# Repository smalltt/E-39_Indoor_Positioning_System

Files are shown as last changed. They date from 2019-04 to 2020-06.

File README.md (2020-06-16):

# E-39 Indoor Positioning System (IPS)

**Project Status:** Ready to manufacture

If you are new to GitHub and would like to create a derivative of this project, please have a look at GitHub instructions to [fork a repo](https://help.github.com/en/articles/fork-a-repo)

## Description

Out of our passion to solve the issue of time waste in the robot creation process, ARC was born. The ARC software platform reduces the time it takes to get from idea to implementation. Since 2011 we have been listening to the challenges robot builders encounter and continue to provide them with an ever expanding toolbox of solutions. Join us on this journey!

We didn't stop at the software, we also made time saving hardware solutions. This IPS reference design is one of them. The IPS has two cameras that alternate frames. One camera has a normal lens with an Infrared blocking filter and the other has an infrared sensitive lens with a daylight blocking filter. A unique feature of this design is that it uses wide angle lenses and can detect the IPS TX at many different angles. We want to share these files with you so you can create your own version for your community and customers to enjoy!

**Features:**
- Combined with the IPS TX, this system can be used for night vision
- SWD Programming port
- Two types of communication modes: USB or EZ-B camera port
- Switch for USB or EZ-B mode
- Replaceable Camera modules
- Replaceable Wide angle lenses
- On-board 3.3V, 2.8V and 1.5V voltage regulation
- 5V tolerant I/O pins
- RGB status indicator
- ARC skill available
- Voltage requirement: 3.2-16VDC (3.3V (EZ-B) or 5V (USB) Typical)
- Current draw: 200mA
- Dimensions: 37.7(W) x 51.5(L) x 16(H) (mm)
- Weight: 11g

**Major components:** 
- STM32F407VET6 32-bit Cortex-M4 ARM microcontroller (custom firmware provided)
- 2 x HDF3M-811 OV2640 2 Megapixel Camera
- TS3DV20812RHHR 1:2 Multiplexer

**Manufacturing notes:** 
1. Supplier: programs custom firmware into the STM32F407VET6 at their facility before sending to manufacturer
2. Supplier: provides pre-built HDF3M-811 OV2640 Cameras with custom ribbon length
3. Supplier: provides HDF3M-811 OV2640 Camera with custom IR filter and Wide angle lens 
4. Supplier: provides HDF3M-811 OV2640 Camera with custom Daylight filter and Wide angle lens 
5. Manufacturer: Dual side placement and soldering of SMT components
6. Manufacturer: Single Side soldering of THT components

This project requires the IPS Transmitter: https://github.com/synthiam/E-44_IPS_Transmitter

## Contents

[**Documentation:**](https://github.com/synthiam/E-39_Indoor_Positioning_System/tree/master/E-39%20Documentation) Schematic PDF, Datasheet PDF, BOM, Assembly PDFs

[**Hardware:**](https://github.com/synthiam/E-39_Indoor_Positioning_System/tree/master/E-39%20Hardware) Altium PCB design File, Altium SCH Design File, Gerbers

[**Firmware:**](https://github.com/synthiam/E-39_Indoor_Positioning_System/tree/master/E-39%20Firmware) Code, Compiled Binary

*Altium Libraries are also available <a href="https://github.com/synthiam/Synthiam_Altium_Librairies">here</a>*

## Photos

<p align="left">


</p>

## ARC Skill

The ARC skill for this reference design is very easy to use! Simply click on the area you'd like the robot to move to and it moves there! 

Link: https://synthiam.com/Software/Manual/Indoor-Positioning-System-17492



## Contact

For profit use of these files requires written consent. Contact partners@synthiam.com. For everyone else, party on!

Synthiam Website: https://synthiam.com

## License

This project is released under the following licenses:

**Hardware:** Creative Commons Plus Attribution-NonCommercial 4.0 International (CC+ BY-NC 4.0)

**Firmware:** Apache 2.0 + “Commons Clause” License Condition v1.0

Please see [LICENSE.md](https://github.com/synthiam/E-39_Indoor_Positioning_System/blob/master/LICENSE.md) for license details.



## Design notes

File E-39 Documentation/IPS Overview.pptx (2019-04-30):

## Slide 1

Project Description:
PCB with 2 cameras and STM32 microcontroller. Both cameras are the same model. The software runs in a loop for ever. In the loop, an image from one camera is captured and transmitted out of the user specified output device (USB or UART). The next time the loop runs, the other camera is used.
The user selects the output device (UART or USB) via a selectable switch on the PCB
Output Packet
The output of each image to USB or UART includes a header. There is a header transmitted before each image. The header identifier begins with EZIMG for one camera, and EZIRC for the other camera. Following the header identifier are 4 bytes representing the image size. And finally, the image data is sent.
Header Examples
- EZIMG<4 bytes image size><image data>
- EZIRC<4 bytes image size><image data>

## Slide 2

Experience Requirements:
- STM32F407VGT6 Microcontroller
- STD Peripheral or HAL
- DCMI
- DMA
- UART
- USB

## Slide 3

Overview:
- Existing code works with UART. Now we’d like to add USB (user selectable by a switch on GPIOA_3)
- we’re okay with code being ported to work with HAL rather than STDPERIPHERAL (up to you)
- PCB has 2 i2c cameras (i2c1 & i2c2)
- STM32 has 1 DMCI interface
- The DMCI of each camera is passed through a TS3DV20812 switching chip controlled by GPIOE_4
Program Start:
- Init the peripherals and DMA, etc.
- Get the user output selected interface from GPIOA_3 switch
- Init the user selected output interface (high is UART and low is USB)
- Init each camera. If i2c fails to initialize the camera, transmit the error message using the appropriate header of the failed camera (0 EZIRC and 1 is EZIMG)
Program Loop:
- The GPIOE_4 alternates between each camera for each irritation of the loop
- The camera dumps its data into the DMA buffer
- Waits until DCMI has completed (while ((DCMI->CR & DCMI_CR_CAPTURE) != 0))
- Send the data in the buffer to the specified output interface. The output interface is user selectable with GPIOA_3 switch on bootup. (high is UART and low is USB)

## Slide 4

Camera 1

Camera 2

Switching IC

I2C1

GPIO

DCMI

I2C2

DMA

Alternate Between Camera

USB or UART selected?

Send DMA Buffer Out USB

Send DMA Buffer Out UART with RTS

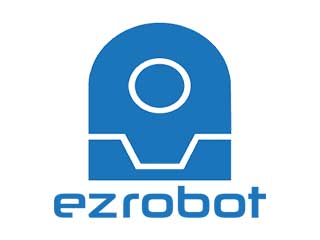
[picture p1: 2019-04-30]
E-39 Firmware/Src/LPS/ImageIntro.jpg

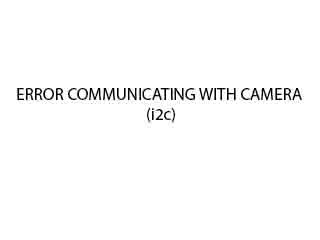
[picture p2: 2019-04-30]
E-39 Firmware/Src/LPS/ErrorCommunicating.jpg

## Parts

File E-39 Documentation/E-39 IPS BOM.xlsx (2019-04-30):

Qty | Description | Manufacturer Part No. | Alternative | Designator | Custom Information | Link
E-39 Indoor Positioning System
1 | 2 layer, Blue soldermask, White silkscreen, ENIG | IPS Printed Circuit Board |  | PCB
1 | 168MHz 32-bit ARM processor | STM32F407VET6 |  | U1 | Needs Main Firmware programmed onto chip before manufacturing | https://www.digikey.ca/product-detail/en/stmicroelectronics/STM32F407VET6/497-12075-ND/2793093
1 | 1:2 Multiplexer | TS3DV20812RHHR |  | U2 |  | https://www.digikey.ca/product-detail/en/texas-instruments/TS3DV20812RHHR/296-27631-1-ND/2345387
1 | 25MHz crystal, 18pF load, 2-SMD package | 7A-25.000MAAJ-T | ABM3-25.000MHZ-D2Y-T | XTAL |  | https://www.digikey.ca/product-detail/en/txc-corporation/7A-25.000MAAJ-T/887-1092-1-ND/2118969
1 | 2.8V Regulator SOT-25 | AP7115-28WG-7 |  | VR1 |  | https://www.digikey.ca/products/en?keywords=AP7115-28WG-7
1 | 1.5V Regulator SOT-25 | AP7331-15WG-7 |  | VR2 |  | https://www.digikey.ca/product-detail/en/diodes-incorporated/AP7331-15WG-7/AP7331-15WG-7DICT-ND/2182591
1 | 3.3V Regulator SOT-25 | SPX3819M5-L-3-3/TR |  | VR3 |  | https://www.digikey.ca/product-detail/en/maxlinear-inc/SPX3819M5-L-3-3-TR/1016-1873-1-ND/3586590
1 | FERRITE BEAD 30 OHM 0603 | CIC10P300NC |  | L1
2 | 4.7kohm 4 x Resistor Array | EXB-38V472JV |  | RA2, RA3
1 | 680ohm 4 x Resistor Array | EXB-38V681JV |  | RA1
1 | 5.1Kohm 0603 Resistor 1% | RC0603FR-075K1L |  | R1
7 | 2.2uF 16V 0603 Ceramic Capacitor | CC0603ZRY5V7BB225 |  | C1, C2, C3, C5, C6, C13, C17
8 | 0.1uF 16V 0603 Ceramic Capacitor | C0603C104K4RACTU |  | C4, C7, C8, C11, C12, C14, C15, C16
2 | 18pF 50V 0603 Ceramic Capacitor | C0603C180J5GACTU |  | C9, C10
1 | PLCC-4 (3528) RGB LED Common Anode | PLCC-4RGBCT-CA |  | RGB |  | http://ledz.com/?p=z.pricelist.other.led
2 | FPC 24pin Header | 2-1734592-4 |  | P1, P2 |  | https://www.digikey.ca/product-detail/en/2-1734592-4/A100288CT-ND/2180623
1 | 6 position JST-PH connector | B6B-PH-K-S(LF)(SN) | 00186 | P3 |  | https://www.digikey.ca/products/en?keywords=B6B-PH-K-S(LF)(SN)
1 | Polyfuse 0.5A 1206 8V | 0ZCJ0050FF2G |  | F1 |  | http://www.digikey.ca/product-detail/en/0ZCJ0050FF2G/507-1802-1-ND/4156236
1 | USB Micro B Connector | 10118194-0001LF |  | USB |  | https://www.digikey.ca/product-detail/en/amphenol-icc-fci/10118194-0001LF/609-4618-1-ND/2785382
1 | DPDT Slide Switch SMD | JS202011SCQN |  | S1 |  | https://www.digikey.ca/product-detail/en/c-k/JS202011SCQN/401-2002-1-ND/1640098
1 | OV2640 Camera + 100° Wide angle lens + Infrared filter | HDF3M-811 |  |  |  | https://www.alibaba.com/product-detail/Cheapest-2Mega-Pixel-Micro-Omnivision-OV2640_60707834599.html
1 | OV2640 Camera + 100° Wide angle lens + Daylight Filter | HDF3M-811 |  |  |  | https://www.alibaba.com/product-detail/Cheapest-2Mega-Pixel-Micro-Omnivision-OV2640_60707834599.html

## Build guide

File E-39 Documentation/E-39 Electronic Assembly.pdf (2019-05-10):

# Assembly Instructions

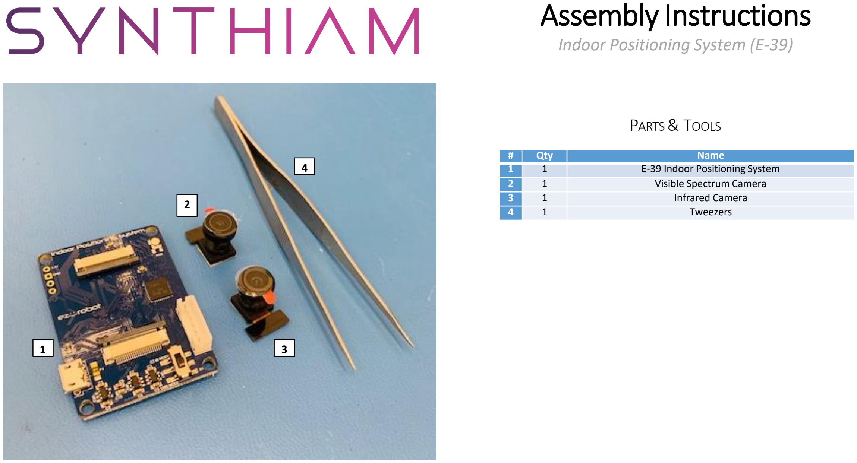
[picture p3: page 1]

# | Qty | Name

1 | 1 | E-39 Indoor Positioning System
2 | 1 | Visible Spectrum Camera
3 | 1 | Infrared Camera
4 | 1 | Tweezers

Indoor Positioning System (E-39)

PARTS & TOOLS

1

2

3

4

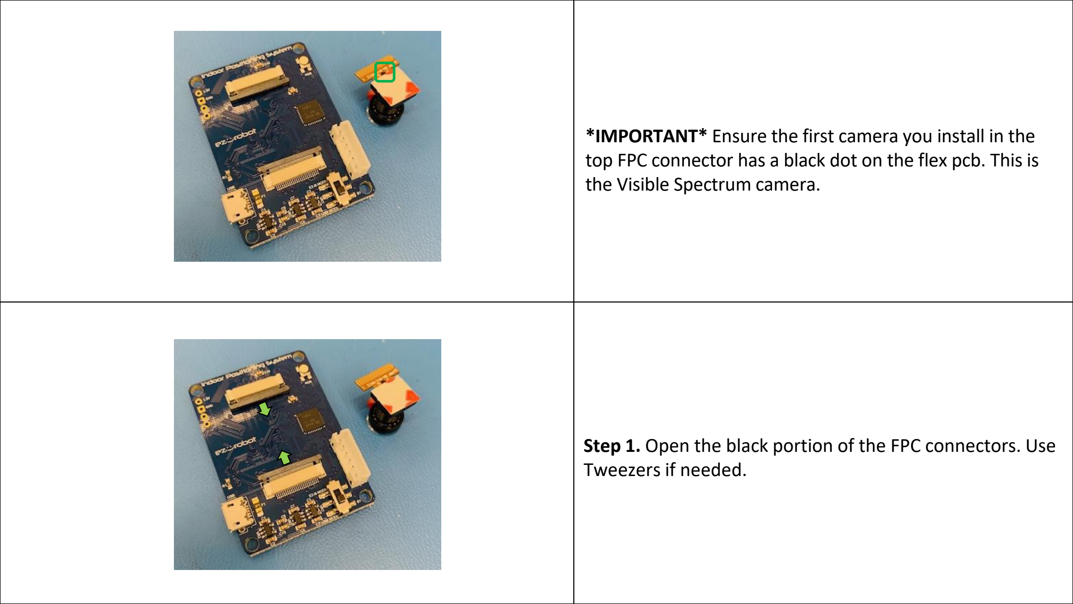
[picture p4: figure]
the Visible Spectrum camera.; Tweezers if needed.

*IMPORTANT* Ensure the first camera you install in the top FPC connector has a black dot on the flex pcb. This is

Step 1. Open the black portion of the FPC connectors. Use

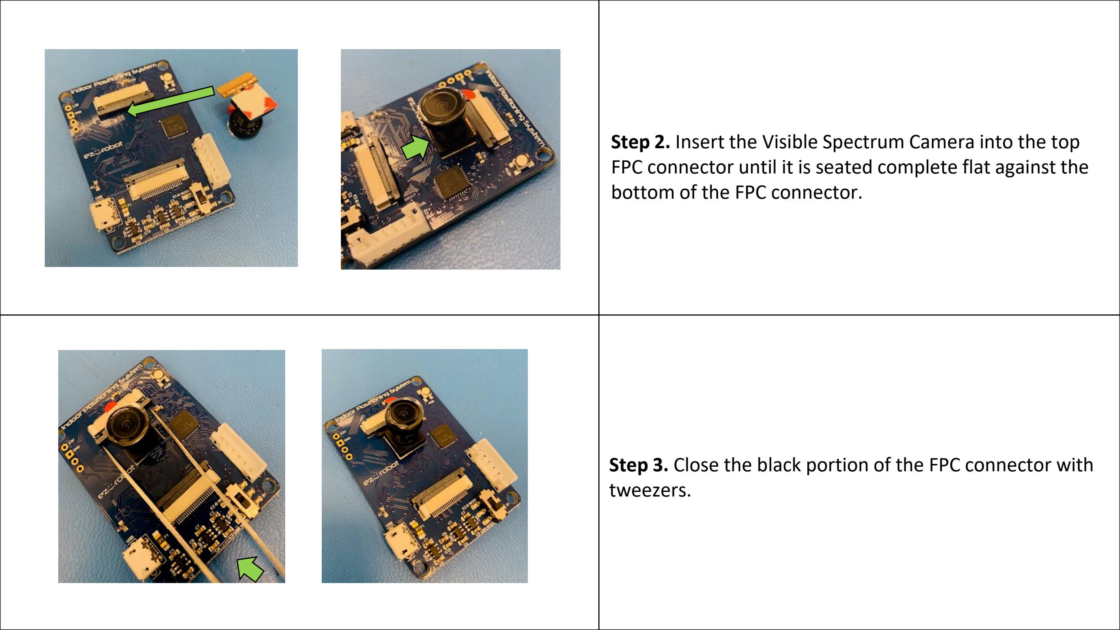
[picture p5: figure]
bottom of the FPC connector.; Infrared Filter must be Removed; tweezers.

Step 2. Insert the Visible Spectrum Camera into the top FPC connector until it is seated complete flat against the
Step 3. Close the black portion of the FPC connector with

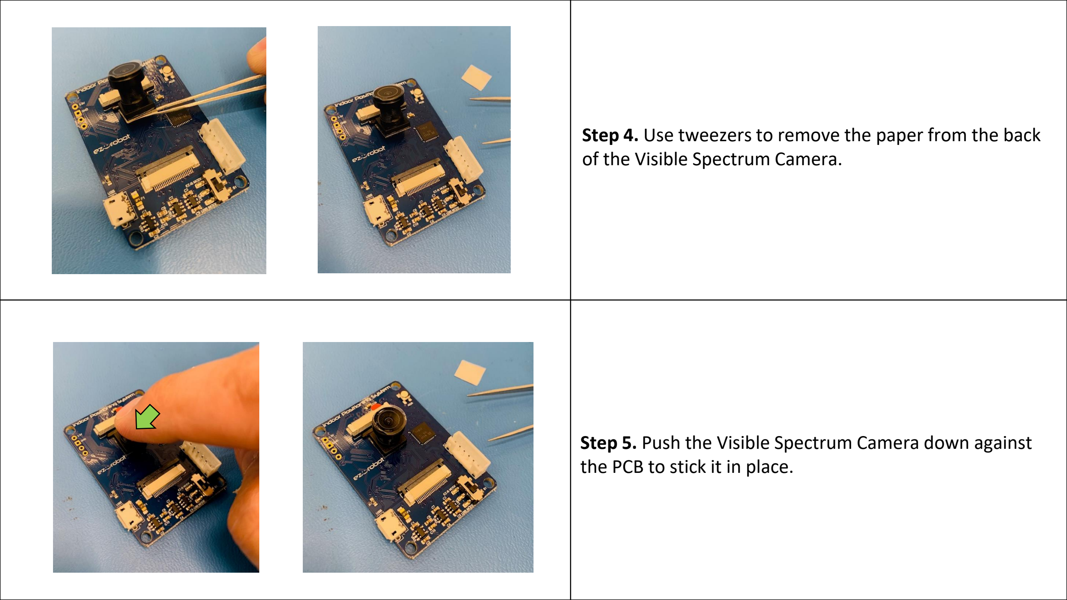
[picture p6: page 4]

Step 4. Use tweezers to remove the paper from the back of the Visible Spectrum Camera.

Infrared Filter must
be Removed
Step 5. Push the Visible Spectrum Camera down against the PCB to stick it in place.

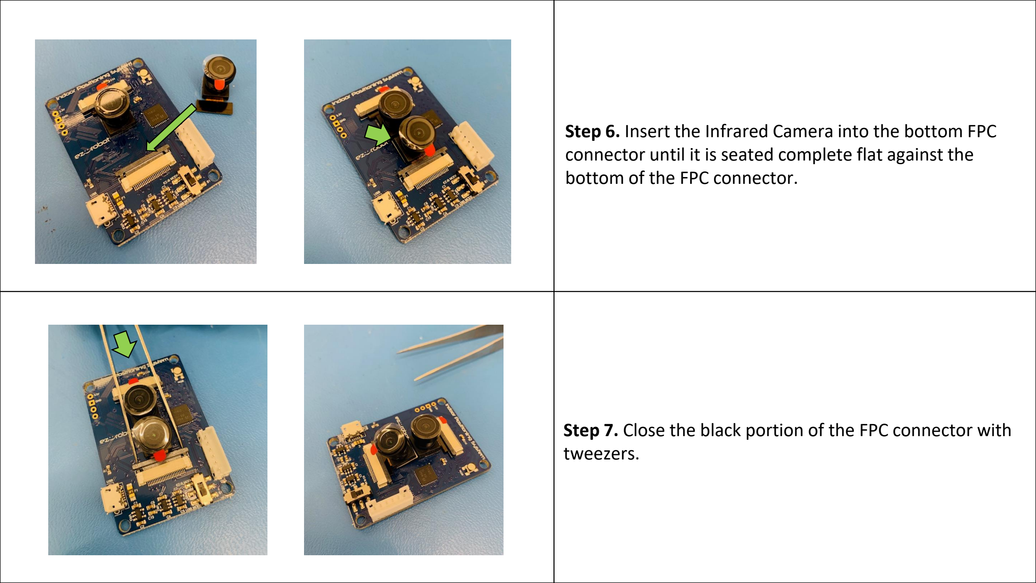
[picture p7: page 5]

Step 6. Insert the Infrared Camera into the bottom FPC connector until it is seated complete flat against the bottom of the FPC connector.

Infrared Filter must
be Removed
Step 7. Close the black portion of the FPC connector with tweezers.

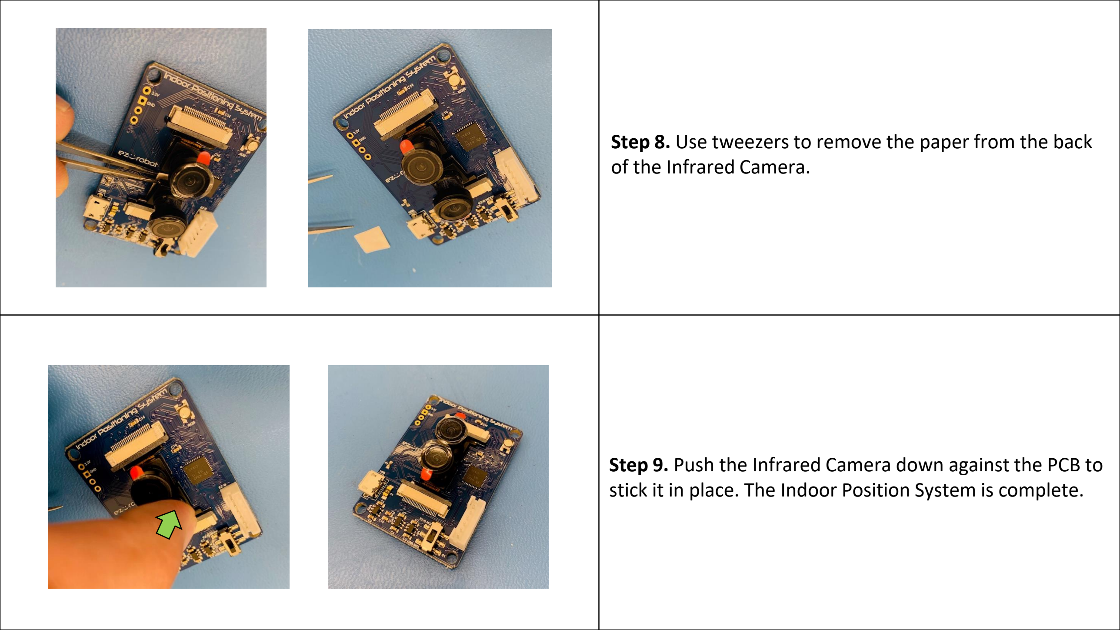
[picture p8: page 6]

Step 8. Use tweezers to remove the paper from the back of the Infrared Camera.

Infrared Filter must
be Removed
Step 9. Push the Infrared Camera down against the PCB to stick it in place. The Indoor Position System is complete.

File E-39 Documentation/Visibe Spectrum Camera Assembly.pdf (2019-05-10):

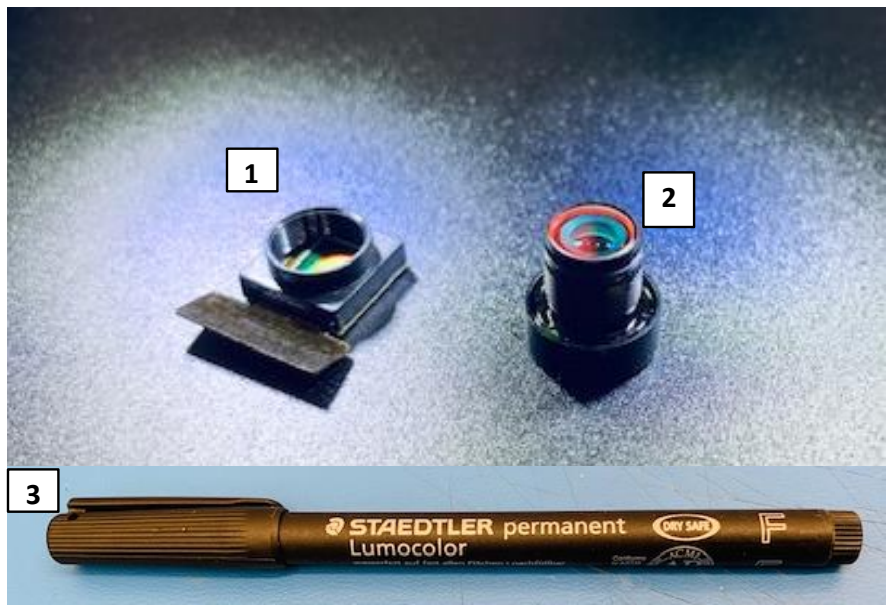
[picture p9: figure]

# | Qty | Name

1 | 1 | HDF-3M-811-WX13 Camera
2 | 1 | 100° Wide Angle Lens with 850nm Infrared filter
3 | 1 | Black permanent Marker

# Assembly Instructions

Visible Spectrum Camera + Wide Angle Lens Rev 4

PARTS & TOOLS

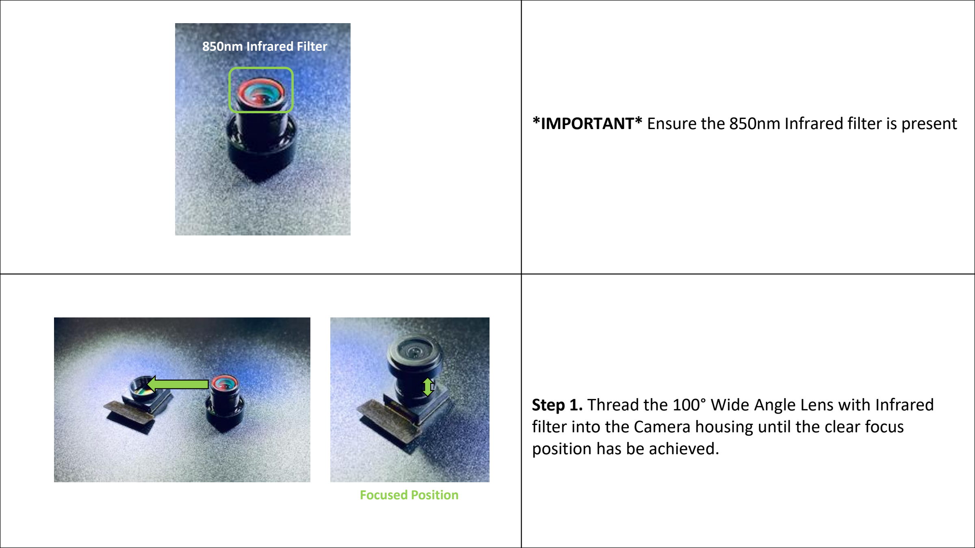
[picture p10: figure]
position has be achieved.; Focused Position; 850nm Infrared Filter

*IMPORTANT* Ensure the 850nm Infrared filter is present

Step 1. Thread the 100° Wide Angle Lens with Infrared filter into the Camera housing until the clear focus

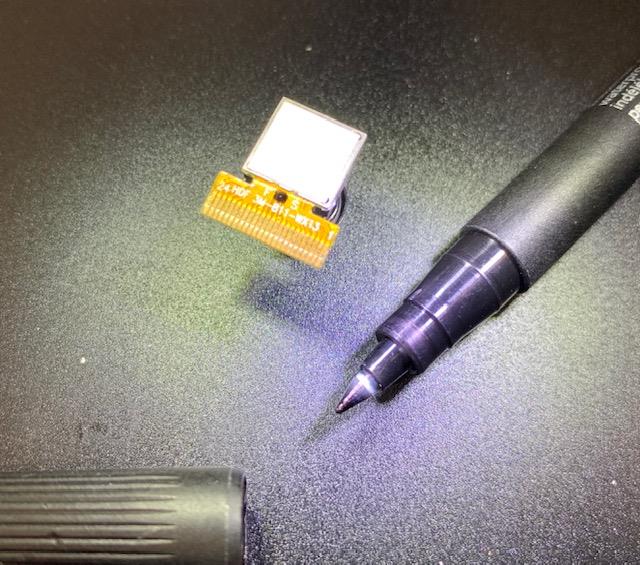
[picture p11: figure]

Step 2. Turn the camera over and place a black mark on the orange flexible PCB with the marker

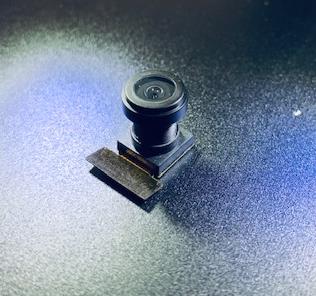
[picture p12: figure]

Visible Spectrum Camera is now complete!

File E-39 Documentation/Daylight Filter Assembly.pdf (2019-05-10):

# Assembly Instructions

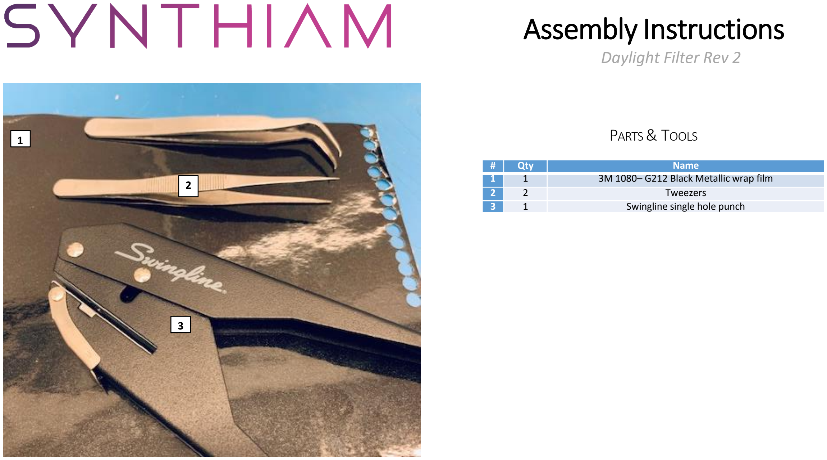
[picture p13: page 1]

# | Qty | Name

1 | 1 | 3M 1080– G212 Black Metallic wrap film
2 | 2 | Tweezers
3 | 1 | Swingline single hole punch

Daylight Filter Rev 2

PARTS & TOOLS 1

2

3

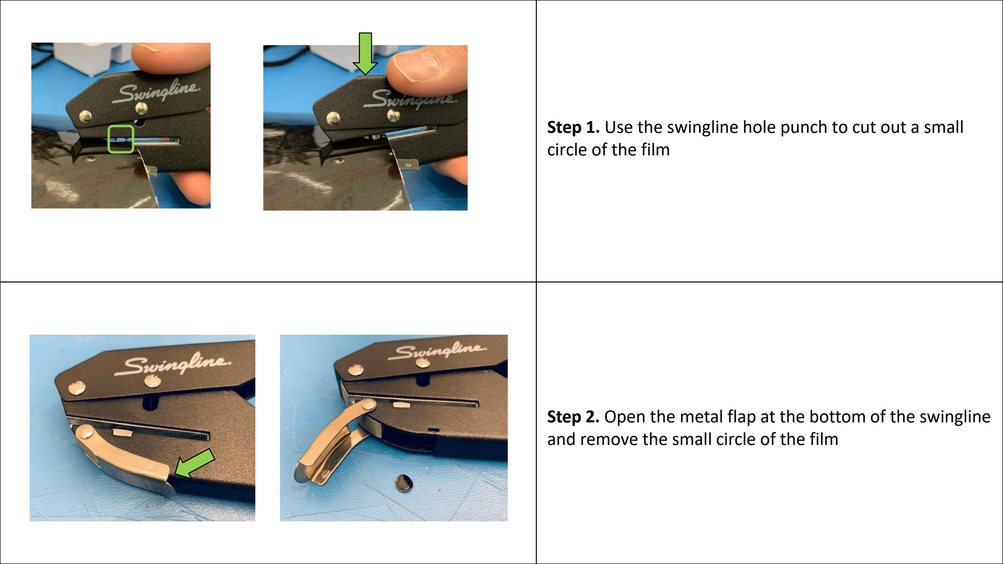
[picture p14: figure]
circle of the film; and remove the small circle of the film; 850nm Infrared Filter

Step 1. Use the swingline hole punch to cut out a small
Step 2. Open the metal flap at the bottom of the swingline

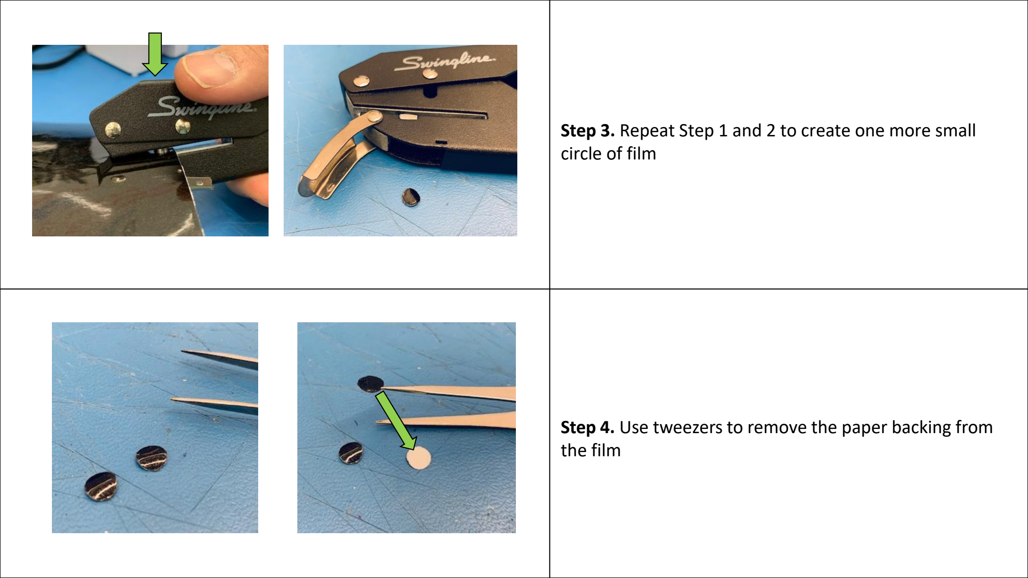
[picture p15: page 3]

Step 3. Repeat Step 1 and 2 to create one more small circle of film
Step 4. Use tweezers to remove the paper backing from the film

850nm Infrared Filter

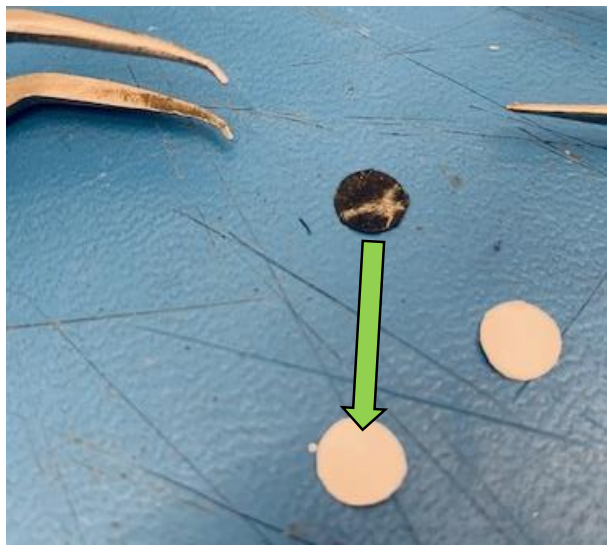
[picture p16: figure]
850nm Infrared Filter

Step 5. Use another set of tweezers to remove the paper backing from the second circle of film

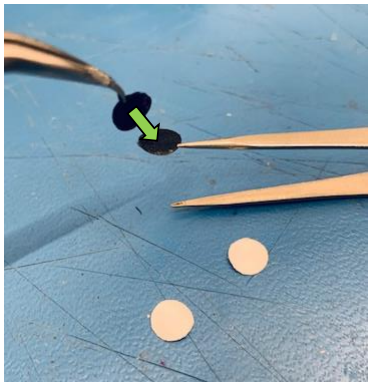
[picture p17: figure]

Step 6. Place the two small circles of film precisely on top of each other with the glue sides touching

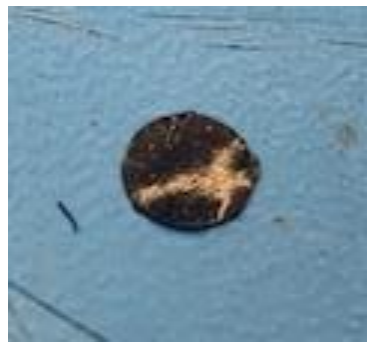
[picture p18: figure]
850nm Infrared Filter

The Daylight Filter is now Complete!

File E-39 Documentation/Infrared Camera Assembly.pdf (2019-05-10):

# Assembly Instructions

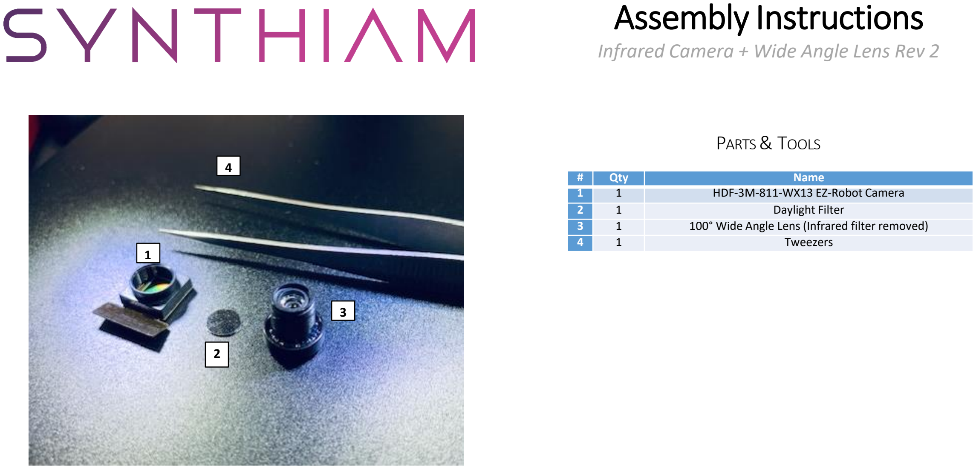
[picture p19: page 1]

# | Qty | Name

1 | 1 | HDF-3M-811-WX13 EZ-Robot Camera
2 | 1 | Daylight Filter
3 | 1 | 100° Wide Angle Lens (Infrared filter removed)
4 | 1 | Tweezers

Infrared Camera + Wide Angle Lens Rev 2

PARTS & TOOLS

1

2

3

4

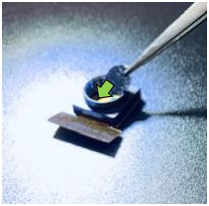
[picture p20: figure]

Step 1. Place the Daylight Filter on top of the camera CCD

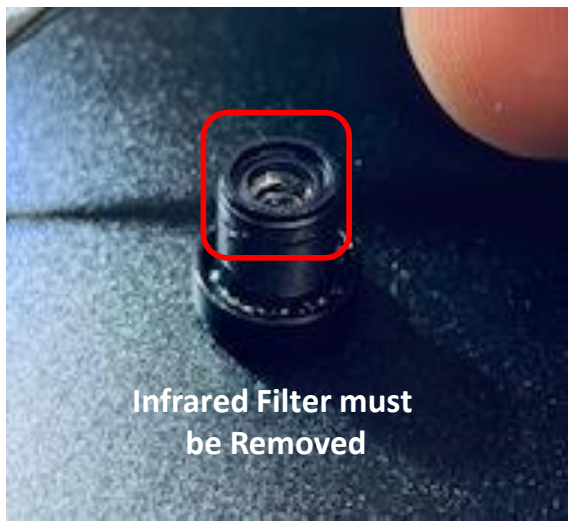
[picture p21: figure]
Infrared Filter must be Removed

*IMPORTANT* Ensure the Infrared filter is removed from the lens

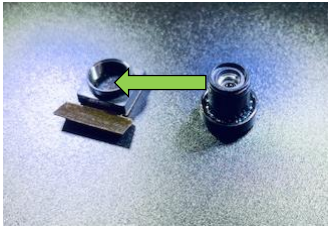
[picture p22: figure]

Step 2. Thread the 100° Wide Angle Lens into the Camera housing until the focused position has be achieved


Infrared Camera is now complete!

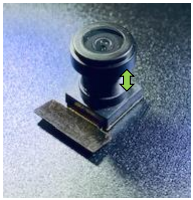
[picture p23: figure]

Focused Position

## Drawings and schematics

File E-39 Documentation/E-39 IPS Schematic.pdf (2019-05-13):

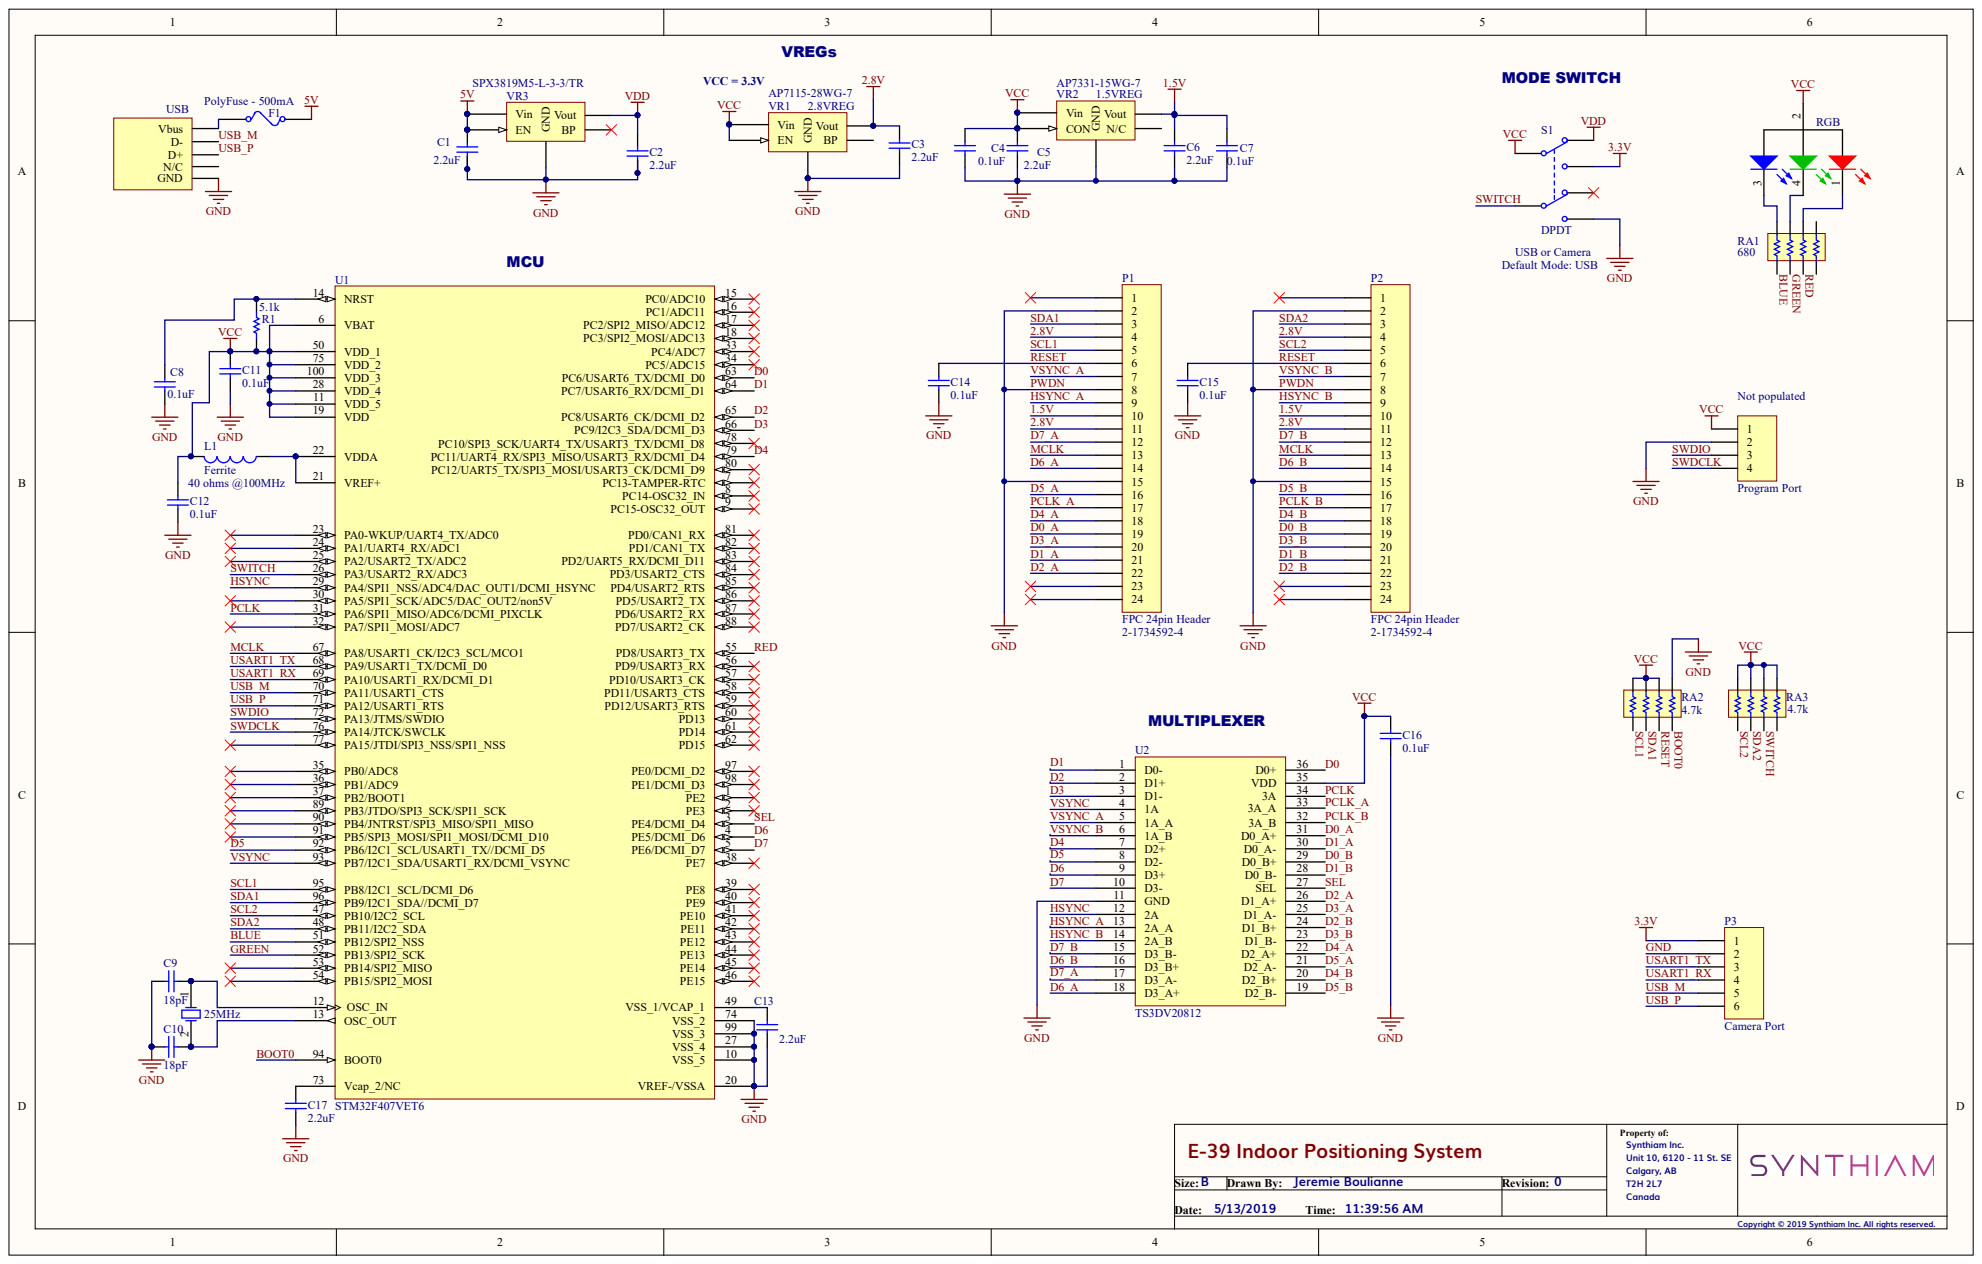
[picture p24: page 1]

E-39 Indoor Positioning System | Property of: Synthiam Inc. Unit 10, 6120 - 11 St. SE Calgary, AB T2H 2L7 Canada

B Size: | Jeremie Boulianne Drawn By: | 0 Revision:
5/13/2019 11:39:56 AM Date: Time:

Copyright © 2019 Synthiam Inc. All rights reserved.

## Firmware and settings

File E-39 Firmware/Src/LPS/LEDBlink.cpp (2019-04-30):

#include "stm32f4xx.h"
#include <stm32f4xx_gpio.h>
#include <stm32f4xx_rcc.h>
#include <stm32f4xx_i2c.h>
#include <stm32f4xx_dcmi.h>
#include <stm32f4xx_dma.h>
#include <stm32f4xx_rcc.h>
#include <stm32f4xx_exti.h>
#include <stm32f4xx_syscfg.h>
#include <stm32f4xx_flash.h>

#include "IOHelper.h"
#include <misc.h>
#include "UARTHelper.h"
#include "USBHelper.h"
#include "EZUtils.h"
#include "SCCB.h"
#include "DCMI_OV2640_INITTABLE.h"

#include "ErrorCommunicating.jpg.h"
#include "ImageIntro.jpg.h"

#define ADDR_WRITE 0x42

#define ADDR_READ 0x43

#define IMAGE_SIZE 65534

uint8_t JpegBuffer[IMAGE_SIZE];

bool _OutputInterface; // high is USB, low is UART

uint8_t _selectedCamera = 0;

void OV2640_DCMI_Config(void) {

  /* VSYNC*/
  GPIO_PinAFConfig(GPIOB, GPIO_PinSource7, GPIO_AF_DCMI);
  /* HSYNC*/
  GPIO_PinAFConfig(GPIOA, GPIO_PinSource4, GPIO_AF_DCMI);
  /* PCLK*/
  GPIO_PinAFConfig(GPIOA, GPIO_PinSource6, GPIO_AF_DCMI);
  /* data0*/
  GPIO_PinAFConfig(GPIOC, GPIO_PinSource6, GPIO_AF_DCMI);
  /* data1*/
  GPIO_PinAFConfig(GPIOC, GPIO_PinSource7, GPIO_AF_DCMI);
  /* data2*/
  GPIO_PinAFConfig(GPIOC, GPIO_PinSource8, GPIO_AF_DCMI);
  /* data3*/
  GPIO_PinAFConfig(GPIOC, GPIO_PinSource9, GPIO_AF_DCMI);
  /* data4*/
  GPIO_PinAFConfig(GPIOC, GPIO_PinSource11, GPIO_AF_DCMI);
  /* data5*/
  GPIO_PinAFConfig(GPIOB, GPIO_PinSource6, GPIO_AF_DCMI);
  /* data6*/
  GPIO_PinAFConfig(GPIOE, GPIO_PinSource5, GPIO_AF_DCMI);
  /* data7*/
  GPIO_PinAFConfig(GPIOE, GPIO_PinSource6, GPIO_AF_DCMI);

  GPIO_InitTypeDef GPIO_InitStructure;
  GPIO_InitStructure.GPIO_Pin = GPIO_Pin_4 | GPIO_Pin_6;
  GPIO_InitStructure.GPIO_Mode = GPIO_Mode_AF;
  GPIO_InitStructure.GPIO_Speed = GPIO_Speed_100MHz;
  GPIO_InitStructure.GPIO_OType = GPIO_OType_PP;
  GPIO_InitStructure.GPIO_PuPd = GPIO_PuPd_UP;
  GPIO_Init(GPIOA, &GPIO_InitStructure);

  GPIO_InitStructure.GPIO_Pin = GPIO_Pin_6 | GPIO_Pin_7;
  GPIO_InitStructure.GPIO_Mode = GPIO_Mode_AF;
  GPIO_InitStructure.GPIO_Speed = GPIO_Speed_100MHz;
  GPIO_InitStructure.GPIO_OType = GPIO_OType_PP;
  GPIO_InitStructure.GPIO_PuPd = GPIO_PuPd_UP;
  GPIO_Init(GPIOB, &GPIO_InitStructure);

  GPIO_InitStructure.GPIO_Pin = GPIO_Pin_6 | GPIO_Pin_7 | GPIO_Pin_8 | GPIO_Pin_9 | GPIO_Pin_11;
  GPIO_InitStructure.GPIO_Mode = GPIO_Mode_AF;
  GPIO_InitStructure.GPIO_Speed = GPIO_Speed_100MHz;
  GPIO_InitStructure.GPIO_OType = GPIO_OType_PP;
  GPIO_InitStructure.GPIO_PuPd = GPIO_PuPd_UP;
  GPIO_Init(GPIOC, &GPIO_InitStructure);

  GPIO_InitStructure.GPIO_Pin = GPIO_Pin_5 | GPIO_Pin_6;
  GPIO_InitStructure.GPIO_Mode = GPIO_Mode_AF;
  GPIO_InitStructure.GPIO_Speed = GPIO_Speed_100MHz;
  GPIO_InitStructure.GPIO_OType = GPIO_OType_PP;
  GPIO_InitStructure.GPIO_PuPd = GPIO_PuPd_UP;
  GPIO_Init(GPIOE, &GPIO_InitStructure);

  DCMI_InitTypeDef DCMI_InitStructure;
  DCMI_InitStructure.DCMI_CaptureMode = DCMI_CaptureMode_SnapShot;
  DCMI_InitStructure.DCMI_ExtendedDataMode = DCMI_ExtendedDataMode_8b;
  DCMI_InitStructure.DCMI_CaptureRate = DCMI_CaptureRate_All_Frame;
  DCMI_InitStructure.DCMI_VSPolarity = DCMI_VSPolarity_Low;
  DCMI_InitStructure.DCMI_HSPolarity = DCMI_HSPolarity_Low;
  DCMI_InitStructure.DCMI_PCKPolarity = DCMI_PCKPolarity_Rising;
  DCMI_InitStructure.DCMI_SynchroMode = DCMI_SynchroMode_Hardware;

  DCMI_Init(&DCMI_InitStructure);

  DMA_Cmd(DMA2_Stream1, ENABLE);

  DCMI_JPEGCmd(ENABLE);

  DCMI_Cmd(ENABLE);
}

void OV2640_DMA_Init(void) {

  /* DMA2 Stream1 Configuration */
  DMA_DeInit(DMA2_Stream1);

  DMA_InitTypeDef  DMA_InitStructure;
  DMA_InitStructure.DMA_Channel = DMA_Channel_1;
  DMA_InitStructure.DMA_PeripheralBaseAddr = (uint32_t)&DCMI->DR;
  DMA_InitStructure.DMA_Memory0BaseAddr = (uint32_t)JpegBuffer;
  DMA_InitStructure.DMA_DIR = DMA_DIR_PeripheralToMemory;
  DMA_InitStructure.DMA_BufferSize = IMAGE_SIZE;
  DMA_InitStructure.DMA_PeripheralInc = DMA_PeripheralInc_Disable;
  DMA_InitStructure.DMA_MemoryInc = DMA_MemoryInc_Enable;
  DMA_InitStructure.DMA_PeripheralDataSize = DMA_PeripheralDataSize_Word;
  DMA_InitStructure.DMA_MemoryDataSize = DMA_MemoryDataSize_Word;
  DMA_InitStructure.DMA_Mode = DMA_Mode_Circular;
  DMA_InitStructure.DMA_Priority = DMA_Priority_VeryHigh;
  DMA_InitStructure.DMA_FIFOMode = DMA_FIFOMode_Disable;
  DMA_InitStructure.DMA_FIFOThreshold = DMA_FIFOThreshold_Full;
  DMA_InitStructure.DMA_MemoryBurst = DMA_MemoryBurst_INC4;
  DMA_InitStructure.DMA_PeripheralBurst = DMA_PeripheralBurst_Single;

  DMA_Init(DMA2_Stream1, &DMA_InitStructure);
}

void MCO1_Init(void) {

  RCC_ClockSecuritySystemCmd(ENABLE);

  GPIO_PinAFConfig(GPIOA, GPIO_PinSource8, GPIO_AF_MCO);

  GPIO_InitTypeDef GPIO_InitStructure;
  GPIO_InitStructure.GPIO_Pin = GPIO_Pin_8;
  GPIO_InitStructure.GPIO_Speed = GPIO_Speed_100MHz;
  GPIO_InitStructure.GPIO_Mode = GPIO_Mode_AF;
  GPIO_InitStructure.GPIO_OType = GPIO_OType_PP;
  GPIO_InitStructure.GPIO_PuPd = GPIO_PuPd_UP;
  GPIO_Init(GPIOA, &GPIO_InitStructure);

  RCC_MCO1Config(RCC_MCO1Source_PLLCLK, RCC_MCO1Div_5);
}

bool OV2640_JPEGConfig(I2C_TypeDef* i2c) {

  uint32_t i;

  //  fputsnl("Sending JPEG Init");
  for (i = 0; i < (sizeof(OV2640_JPEG_INIT) / 2); i++) {

    uint8_t r = DCMI_SingleRandomWrite(i2c, OV2640_JPEG_INIT[i][0], OV2640_JPEG_INIT[i][1]);

    if (r == 0xff)
      return false;

    DelayMS(1);
  }

  //  fputsnl("Sending YUV422 Init");
  for (i = 0; i < (sizeof(OV2640_YUV422) / 2); i++) {

    uint8_t r = DCMI_SingleRandomWrite(i2c, OV2640_YUV422[i][0], OV2640_YUV422[i][1]);

    if (r == 0xff)
      return false;

    DelayMS(1);
  }

  //  fputsnl("Sending JPEG but not init");
  for (i = 0; i < (sizeof(OV2640_JPEG) / 2); i++) {

    uint8_t r = DCMI_SingleRandomWrite(i2c, OV2640_JPEG[i][0], OV2640_JPEG[i][1]);

    if (r == 0xff)
      return false;

    DelayMS(1);
  }

  for (i = 0; i < (sizeof(OV2640_640x480_JPEG) / 2); i++) {

    uint8_t r = DCMI_SingleRandomWrite(i2c, OV2640_640x480_JPEG[i][0], OV2640_640x480_JPEG[i][1]);

    if (r == 0xff)
      return false;

    DelayMS(1);
  }

  return true;
}

void SCCB_WriteRegs(I2C_TypeDef* i2c, const uint8_t* pbuf) {

  while (1) {

    if ((*pbuf == 0) && (*(pbuf + 1) == 0)) {

      break;
    }
    else {

      DCMI_SingleRandomWrite(i2c, *pbuf++, *pbuf++);
    }
  }
}

void StatusLED(bool red, bool green, bool blue) {

  if (red)
    SetLow(GPIOD, GPIO_Pin_8);
  else
    SetHigh(GPIOD, GPIO_Pin_8);

  if (green)
    SetLow(GPIOB, GPIO_Pin_13);
  else
    SetHigh(GPIOB, GPIO_Pin_13);

  if (blue)
    SetLow(GPIOB, GPIO_Pin_12);
  else
    SetHigh(GPIOB, GPIO_Pin_12);
}

void OV2640_AutoExposure(I2C_TypeDef* i2c, uint8_t level) {

  switch (level) {

  case 0:
    SCCB_WriteRegs(i2c, OV2640_AUTOEXPOSURE_LEVEL0);
    break;
  case 1:
    SCCB_WriteRegs(i2c, OV2640_AUTOEXPOSURE_LEVEL1);
    break;
  case 2:
    SCCB_WriteRegs(i2c, OV2640_AUTOEXPOSURE_LEVEL2);
    break;
  case 3:
    SCCB_WriteRegs(i2c, OV2640_AUTOEXPOSURE_LEVEL3);
    break;
  case 4:
    SCCB_WriteRegs(i2c, OV2640_AUTOEXPOSURE_LEVEL4);
    break;
  default:
    SCCB_WriteRegs(i2c, OV2640_AUTOEXPOSURE_LEVEL0);
    break;
  }

  DelayMS(1);
}

void flashStatus(int delay, int count) {

  for (int x = 0; x < count; x++) {

    StatusLED(false, true, false);
    DelayMS(delay);

    StatusLED(false, false, false);
    DelayMS(delay);
  }
}

void OV2640_BrightnessContrastConfig(I2C_TypeDef* i2c, uint8_t Contrast, uint8_t brightness) {

  DCMI_SingleRandomWrite(i2c, 0xff, 0x00);
  DCMI_SingleRandomWrite(i2c, 0x7c, 0x00);
  DCMI_SingleRandomWrite(i2c, 0x7d, 0x04);
  DCMI_SingleRandomWrite(i2c, 0x7c, 0x07);
  DCMI_SingleRandomWrite(i2c, 0x7d, 0x20);
  DCMI_SingleRandomWrite(i2c, 0x7d, Contrast);
  DCMI_SingleRandomWrite(i2c, 0x7d, brightness);
  DCMI_SingleRandomWrite(i2c, 0x7d, 0x06);
}

void OV2640_BrightnessConfig(I2C_TypeDef* i2c, uint8_t Brightness) {

  DCMI_SingleRandomWrite(i2c, 0xff, 0x00);
  DCMI_SingleRandomWrite(i2c, 0x7c, 0x00);
  DCMI_SingleRandomWrite(i2c, 0x7d, 0x04);
  DCMI_SingleRandomWrite(i2c, 0x7c, 0x09);
  DCMI_SingleRandomWrite(i2c, 0x7d, Brightness);
  DCMI_SingleRandomWrite(i2c, 0x7d, 0x00);
}

void SetCompressionValue(I2C_TypeDef* i2c, int value) {

  //if (value < 8)
  //  value = 8;
  //else if (value > 55)
  //  value = 55;

  DCMI_SingleRandomWrite(i2c, 0xFF, 0x00);
  DelayMS(1);
  DCMI_SingleRandomWrite(i2c, 0x44, value);
  DelayMS(1);
  //DCMI_SingleRandomWrite(i2c, 0xda, 0x10);
  //DelayMS(1);
  //DCMI_SingleRandomWrite(i2c, 0xe0, 0x00);
  //DelayMS(1);
  //DCMI_SingleRandomWrite(i2c, 0xFF, 0x01);
  //DelayMS(1);
  //DCMI_SingleRandomWrite(i2c, 0x04, 0x08);
  //DelayMS(1);
}

void SetBandingConfig(I2C_TypeDef* i2c, int value) {

  // 0 = 60
  // 1 = 50
  // 2 = Auto

  DCMI_SingleRandomWrite(i2c, 0xff, 0x01);
  DelayMS(1);

  switch (value) {
  case 0:
    DCMI_SingleRandomWrite(i2c, 0x0c, 0x3c);
    break;
  case 1:
    DCMI_SingleRandomWrite(i2c, 0x0c, 0x38);
    break;
  case 2:
    DCMI_SingleRandomWrite(i2c, 0x0c, 0x32);
    break;
  }

  DelayMS(1);
}

void ImageFlip(I2C_TypeDef* i2c, bool vFlip, bool hFlip) {

  uint8_t defaultVal;

  if (vFlip)
    defaultVal = defaultVal | 64;

  if (hFlip)
    defaultVal = defaultVal | 128;

  defaultVal = defaultVal | 16;
  defaultVal = defaultVal | 8;

  DCMI_SingleRandomWrite(i2c, 0xff, 0x01); // program sensor (not dsp)
  DelayMS(1);

  DCMI_SingleRandomWrite(i2c, 0x04, defaultVal);
  DelayMS(1);
}

// Returns true if the OrigVal is within the LowLimit and HighLimit range
bool isBetween(uint64_t origVal, uint64_t lowLimit, uint64_t highLimit) {

  if (origVal > lowLimit && origVal < highLimit)
    return true;

  return false;
}

void putImage(uint8_t *dataBuffer, int32_t size) {

  if (_selectedCamera) {

    if (_OutputInterface) {

      UsbPuts("EZIRC");
      UsbPutc32(size);
      VCP_DataTx(dataBuffer, size);
    }
    else {

      fputs("EZIRC");
      fputc32(size);
      fputArrayViaDMA(dataBuffer, size);
    }
  }
  else {

    if (_OutputInterface) {

      UsbPuts("EZIMG");
      UsbPutc32(size);
      VCP_DataTx(dataBuffer, size);
    }
    else {

      fputs("EZIMG");
      fputc32(size);
      fputArrayViaDMA(dataBuffer, size);
    }
  }
}

void sendCameraErrorInitImage() {

  bool flashy = false;

  while (true) {

    putImage((uint8_t *)ErrorCommunicating, ErrorCommunicating_Size);

    if (flashy)
      StatusLED(true, false, false);
    else
      StatusLED(false, false, false);

    flashy = !flashy;
  }
}

void EZBLoop() {

  // always start with the first camera
  _selectedCamera = 0;

  while (true) {

    _selectedCamera = !_selectedCamera;

    StatusLED(false, false, true);

    if (_selectedCamera)
      SetHigh(GPIOE, GPIO_Pin_4);
    else
      SetLow(GPIOE, GPIO_Pin_4);

    DMA2_Stream1->NDTR = IMAGE_SIZE;

    DMA_Cmd(DMA2_Stream1, ENABLE);

    while (DMA_GetCmdStatus(DMA2_Stream1) == DISABLE)
      ;

    DCMI_CaptureCmd(ENABLE);

    while ((DCMI->CR & DCMI_CR_CAPTURE) != 0)
      ;

    StatusLED(false, true, false);

    DMA_Cmd(DMA2_Stream1, DISABLE);

    while (DMA_GetCmdStatus(DMA2_Stream1) == ENABLE)
      ;

    int tmpSize = (IMAGE_SIZE - DMA2_Stream1->NDTR) * 4;

    putImage(JpegBuffer, tmpSize);
  }
}

int main() {

  RCC_AHB1PeriphClockCmd(RCC_AHB1Periph_GPIOA, ENABLE);
  RCC_AHB1PeriphClockCmd(RCC_AHB1Periph_GPIOB, ENABLE);
  RCC_AHB1PeriphClockCmd(RCC_AHB1Periph_GPIOC, ENABLE);
  RCC_AHB1PeriphClockCmd(RCC_AHB1Periph_GPIOD, ENABLE);
  RCC_AHB1PeriphClockCmd(RCC_AHB1Periph_GPIOE, ENABLE);

  RCC_AHB2PeriphClockCmd(RCC_AHB2Periph_DCMI, ENABLE);   // DCMI
  RCC_APB2PeriphClockCmd(RCC_APB2Periph_USART1, ENABLE); // USART1
  RCC_AHB1PeriphClockCmd(RCC_AHB1Periph_DMA2, ENABLE);   // USART1 DCMI
  RCC_APB1PeriphClockCmd(RCC_APB1Periph_I2C1, ENABLE);   // Camera #1 I2C
  RCC_APB1PeriphClockCmd(RCC_APB1Periph_I2C2, ENABLE);   // Camera #2 I2C

  // Camera Select
  // LOW = i2c1
  // HIGH = i2c2
  SetIODirection(GPIOE, GPIO_Pin_4, GPIO_Mode_OUT);

  // Output Select Switch
  // LOW = USB
  // HIGH = UART (3,333,333 bps)
  SetIODirection(GPIOA, GPIO_Pin_3, GPIO_Mode_IN);

  // Set and Initalize the output device
  _OutputInterface = GetPin(GPIOA, GPIO_Pin_3);

  if (_OutputInterface)
    InitUSB();
  else
    InitUART(3333333);

  // Status LED
  SetIODirection(GPIOD, GPIO_Pin_8, GPIO_Mode_OUT); // red
  SetIODirection(GPIOB, GPIO_Pin_13, GPIO_Mode_OUT); // green
  SetIODirection(GPIOB, GPIO_Pin_12, GPIO_Mode_OUT); // blue

  for (int x = 0; x < 3; x++) {

    StatusLED(true, false, false);
    DelayMS(250);
    StatusLED(false, true, false);
    DelayMS(250);
    StatusLED(false, false, true);
    DelayMS(250);
  }

  StatusLED(false, false, false);

  SCCB_GPIO_Config();

  StatusLED(true, true, true);

  MCO1_Init();

  OV2640_DCMI_Config();

  OV2640_DMA_Init();

  _selectedCamera = 0;
  if (!OV2640_JPEGConfig(Open407V_SCCB_1))
    sendCameraErrorInitImage();

  _selectedCamera = 1;
  if (!OV2640_JPEGConfig(Open407V_SCCB_2))
    sendCameraErrorInitImage();

  OV2640_BrightnessContrastConfig(Open407V_SCCB_1, 30, 30);
  OV2640_BrightnessContrastConfig(Open407V_SCCB_2, 12, 12);

  SetCompressionValue(Open407V_SCCB_1, 10);
  SetCompressionValue(Open407V_SCCB_2, 10);

  // auto light banding
  SetBandingConfig(Open407V_SCCB_1, 2);
  SetBandingConfig(Open407V_SCCB_2, 2);

  ImageFlip(Open407V_SCCB_1, true, true);

  EZBLoop();
}

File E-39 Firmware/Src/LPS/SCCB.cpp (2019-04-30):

#include "SCCB.h"
#include "UARTHelper.h"

volatile uint32_t  DCMI_TIMEOUT_MAX = SCCB_Open407V_FLAG_TIMEOUT;

void SCCB_GPIO_Config(void) {

  GPIO_InitTypeDef  GPIO_InitStructure;

  // I2C #1
  // -------------------------------------------------------------------------------------------
  GPIO_PinAFConfig(GPIOB, GPIO_PinSource8, GPIO_AF_I2C1);
  GPIO_PinAFConfig(GPIOB, GPIO_PinSource9, GPIO_AF_I2C1);

  GPIO_InitStructure.GPIO_Pin = GPIO_Pin_8 | GPIO_Pin_9;
  GPIO_InitStructure.GPIO_Mode = GPIO_Mode_AF;
  GPIO_InitStructure.GPIO_OType = GPIO_OType_OD;
  GPIO_InitStructure.GPIO_Speed = GPIO_Speed_100MHz;
  GPIO_InitStructure.GPIO_PuPd = GPIO_PuPd_UP;
  GPIO_Init(GPIOB, &GPIO_InitStructure);

  I2C_DeInit(Open407V_SCCB_1);
  I2C_InitTypeDef  SCCB_InitStructure;
  SCCB_InitStructure.I2C_Mode = I2C_Mode_I2C;
  SCCB_InitStructure.I2C_DutyCycle = I2C_DutyCycle_2;
  SCCB_InitStructure.I2C_OwnAddress1 = SCCB_SLAVE_ADDRESS7;
  SCCB_InitStructure.I2C_Ack = I2C_Ack_Enable;
  SCCB_InitStructure.I2C_AcknowledgedAddress = I2C_AcknowledgedAddress_7bit;
  SCCB_InitStructure.I2C_ClockSpeed = SCCB_SPEED;

  I2C_Init(Open407V_SCCB_1, &SCCB_InitStructure);
  I2C_Cmd(Open407V_SCCB_1, ENABLE);

  I2C_AcknowledgeConfig(Open407V_SCCB_1, ENABLE);
  
  // I2C #1
  // -------------------------------------------------------------------------------------------
  GPIO_PinAFConfig(GPIOB, GPIO_PinSource10, GPIO_AF_I2C2);
  GPIO_PinAFConfig(GPIOB, GPIO_PinSource11, GPIO_AF_I2C2);

  GPIO_InitStructure.GPIO_Pin = GPIO_Pin_10 | GPIO_Pin_11;
  GPIO_InitStructure.GPIO_Mode = GPIO_Mode_AF;
  GPIO_InitStructure.GPIO_OType = GPIO_OType_OD;
  GPIO_InitStructure.GPIO_Speed = GPIO_Speed_100MHz;
  GPIO_InitStructure.GPIO_PuPd = GPIO_PuPd_UP;
  GPIO_Init(GPIOB, &GPIO_InitStructure);

  I2C_DeInit(Open407V_SCCB_2);
  SCCB_InitStructure.I2C_Mode = I2C_Mode_I2C;
  SCCB_InitStructure.I2C_DutyCycle = I2C_DutyCycle_2;
  SCCB_InitStructure.I2C_OwnAddress1 = SCCB_SLAVE_ADDRESS7;
  SCCB_InitStructure.I2C_Ack = I2C_Ack_Enable;
  SCCB_InitStructure.I2C_AcknowledgedAddress = I2C_AcknowledgedAddress_7bit;
  SCCB_InitStructure.I2C_ClockSpeed = SCCB_SPEED;

  I2C_Init(Open407V_SCCB_2, &SCCB_InitStructure);
  I2C_Cmd(Open407V_SCCB_2, ENABLE);

  I2C_AcknowledgeConfig(Open407V_SCCB_2, ENABLE);
}

uint8_t DCMI_SingleRandomWrite(I2C_TypeDef* i2c, uint8_t Reg, uint8_t Data) {

  //fputs("Reg: ");
  //fputh(Reg);
  //fputs(" = ");
  //fputh(Data);
  //fputsnl();

  uint32_t timeout = DCMI_TIMEOUT_MAX;

  /* Generate the Start Condition */
  I2C_GenerateSTART(i2c, ENABLE);

  /* Test on I2C2 EV5 and clear it */
  timeout = DCMI_TIMEOUT_MAX; /* Initialize timeout value */

  while (!I2C_CheckEvent(i2c, I2C_EVENT_MASTER_MODE_SELECT))
    if ((timeout--) == 0) return 0xFF;

  /*-----------------------------------------------------------------------------------*/
  /* Send DCMI selcted device slave Address for write */
  I2C_Send7bitAddress(i2c, OV2640_DEVICE_WRITE_ADDRESS, I2C_Direction_Transmitter);

  /* Test on I2C2 EV6 and clear it */
  timeout = DCMI_TIMEOUT_MAX; /* Initialize timeout value */

  while (!I2C_CheckEvent(i2c, I2C_EVENT_MASTER_TRANSMITTER_MODE_SELECTED))
    if ((timeout--) == 0) return 0xFF;

  /*-----------------------------------------------------------------------------------*/
  /* Send I2C2 location address LSB */
  I2C_SendData(i2c, (uint8_t)(Reg));

  /* Test on I2C2 EV8 and clear it */
  timeout = DCMI_TIMEOUT_MAX; /* Initialize timeout value */

  while (!I2C_CheckEvent(i2c, I2C_EVENT_MASTER_BYTE_TRANSMITTED))
    if ((timeout--) == 0) return 0xFF;

  /*-----------------------------------------------------------------------------------*/
  /* Send Data */
  I2C_SendData(i2c, Data);

  /* Test on I2C2 EV8 and clear it */
  timeout = DCMI_TIMEOUT_MAX; /* Initialize timeout value */

  while (!I2C_CheckEvent(i2c, I2C_EVENT_MASTER_BYTE_TRANSMITTED))
    if ((timeout--) == 0) return 0xFF;

  /*-----------------------------------------------------------------------------------*/
  /* Send I2C2 STOP Condition */
  I2C_GenerateSTOP(i2c, ENABLE);

  /* If operation is OK, return 0 */
  return 0;
}

/**
  * @brief  Reads a byte from a specific Camera register
  * @param  Device: OV2640 write address.
  * @param  Addr: OV2640 register address.
  * @retval data read from the specific register or 0xFF if timeout condition
  *         occured.
  */
uint8_t DCMI_SingleRandomRead(I2C_TypeDef* i2c, uint8_t Reg, uint8_t *Data) {

  uint32_t timeout = DCMI_TIMEOUT_MAX;

  /* Clear AF flag if arised */
  I2C2->SR1 |= (uint16_t)0x0400;

  /* Generate the Start Condition */
  I2C_GenerateSTART(i2c, ENABLE);

  /* Test on I2C2 EV5 and clear it */
  timeout = DCMI_TIMEOUT_MAX; /* Initialize timeout value */

  while (!I2C_CheckEvent(i2c, I2C_EVENT_MASTER_MODE_SELECT)) {
    /* If the timeout delay is exeeded, exit with error code */
    if ((timeout--) == 0) return 0xFF;
  }

  /*-----------------------------------------------------------------------------------*/
  /* Send DCMI selcted device slave Address for write */
  I2C_Send7bitAddress(i2c, OV2640_DEVICE_READ_ADDRESS, I2C_Direction_Transmitter);

  /* Test on I2C2 EV6 and clear it */
  timeout = DCMI_TIMEOUT_MAX; /* Initialize timeout value */

  while (!I2C_CheckEvent(i2c, I2C_EVENT_MASTER_TRANSMITTER_MODE_SELECTED)) {
    /* If the timeout delay is exeeded, exit with error code */
    if ((timeout--) == 0) return 0xFF;
  }

  /*-----------------------------------------------------------------------------------*/
  /* Send I2C2 location address LSB */
  I2C_SendData(i2c, (uint8_t)(Reg));

  /* Test on I2C2 EV8 and clear it */
  timeout = DCMI_TIMEOUT_MAX; /* Initialize timeout value */

  while (!I2C_CheckEvent(i2c, I2C_EVENT_MASTER_BYTE_TRANSMITTED)) {
    /* If the timeout delay is exeeded, exit with error code */
    if ((timeout--) == 0) return 0xFF;
  }

  /* Clear AF flag if arised */
  I2C2->SR1 |= (uint16_t)0x0400;
  /*-----------------------------------------------------------------------------------*/
  /* Prepare Stop after receiving data */
  I2C_GenerateSTOP(i2c, ENABLE);

  /*-----------------------------------------------------------------------------------*/
  /* Generate the Start Condition */
  I2C_GenerateSTART(i2c, ENABLE);

  /* Test on I2C2 EV6 and clear it */
  timeout = DCMI_TIMEOUT_MAX; /* Initialize timeout value */

  while (!I2C_CheckEvent(i2c, I2C_EVENT_MASTER_MODE_SELECT)) {

    /* If the timeout delay is exeeded, exit with error code */
    if ((timeout--) == 0) return 0xFF;
  }

  /*-----------------------------------------------------------------------------------*/
  /* Send DCMI selcted device slave Address for write */
  I2C_Send7bitAddress(i2c, OV2640_DEVICE_READ_ADDRESS, I2C_Direction_Receiver);

  /* Test on I2C2 EV6 and clear it */
  timeout = DCMI_TIMEOUT_MAX; /* Initialize timeout value */
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
